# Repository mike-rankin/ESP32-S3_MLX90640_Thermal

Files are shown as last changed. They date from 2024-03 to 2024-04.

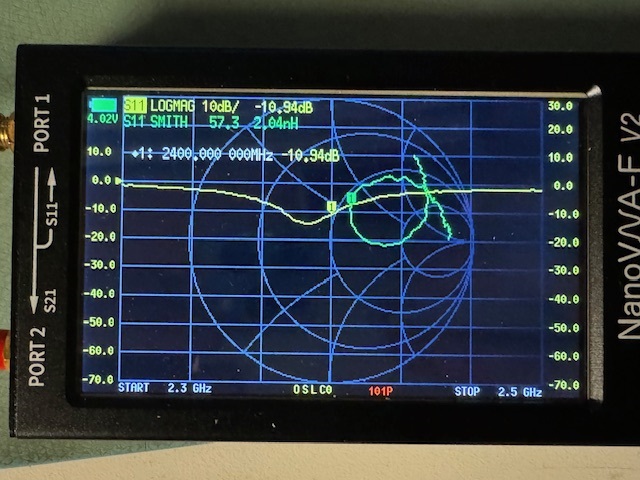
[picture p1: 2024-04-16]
PCB/Antenna_Perfect_Performance.jpg

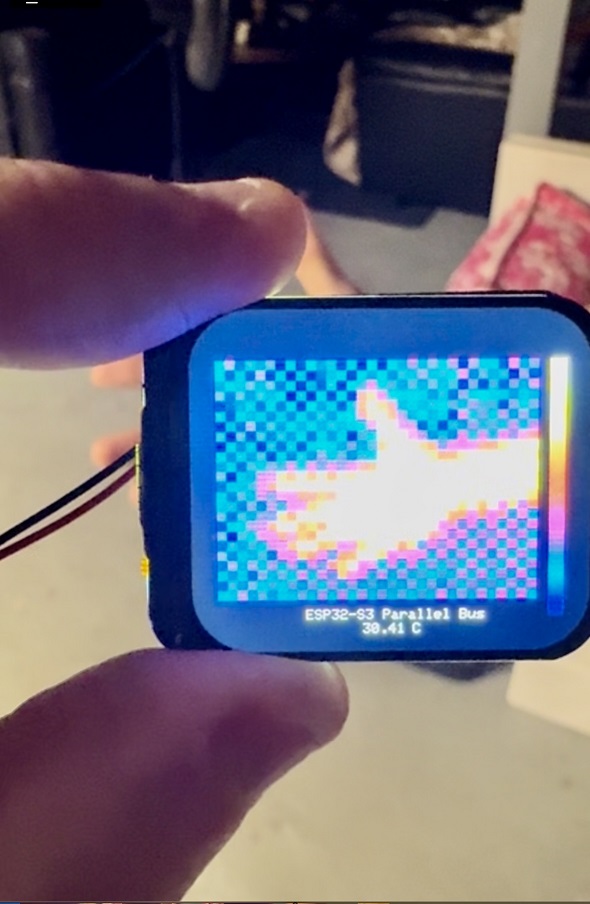
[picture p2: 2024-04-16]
Images/Hand.jpg

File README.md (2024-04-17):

# ESP32-S3_MLX90640_Thermal

An assembled and tested board is available at Tindie: https://www.tindie.com/products/miker/esp32-s3-mlx90640-thermal-image-board/<br/>

This project has gone through several revisions over several months. This latest uses a pcb track antenna instead of the chip type. Tuning has gone well and it seems to perform well. This version uses an ESP32-S3 processor allowing everything to fit on the backside of a 1.69" screen. An 8-bit bus improves the refresh dramatically over traditional spi displays. It is powered by a USB-C connector or small LiPO battery<br/>
Two right angle pushbuttons are on one side if needed and two small vertical ones needed only when first powering up the board to bring up the com port. The thermal code provided is rough but shows basic functionality. Hopefully it can be of some help allowing you to make improvements. The design files are all available if you would like to assemble your own and change the design yourself. <br/>
<br/>

**Hardware used on this board <br/>**
-Processor (ESP32-S3FN8)<br/>
-1.69" LCD (https://www.buydisplay.com/1-69-inch-color-280x240-round-rectangle-ips-tft-lcd-display-panel-st7789)<br/>
-3.3V LDO (HT7833)<br/>
-LiPo charger (MCP73831T-2ACI)<br/>
-LiPo connector (1.25mm JST type)<br/>
-Thermal Sensor (MLX90640ESF-BAB-000-TU)<br/>
-LiPo battery monitor (MAX17048G+)<br/>
<br/>

**FAQ** <br/> 
**How do I updload my own sketch?<br/>** 
**-Plug the board into your pc. If your com port appears and disappears over and over, hold down the B (Boot button), tap on the R (Reset) button, let go of the Boot button. This should hold the com port<br/>**
**-Install the latest Arduino IDE, install the ESP32 Board libraries, Install the sensor libraries, Install an older TFT_eSPI library 2.5.43 or compile issues may appear, delete the User_Setup.h and User_Setup_Select.h files and replace with mine<br/>**
**-Upload your sketch<br/>**
<br/>
**Where do I get a battery?<br/>**
**-Source a 300mAh to 500mAh LiPo with a 1.25mm battery from Aliexpress. Just make sure the positive and negative wires are in the correct locations as noted on the board. If not, they can be removed by lifting the tab and swapping around<br/>**
<br/>
**Why does my battery never charge?<br/>**
**-The charger cannot power the board and charge the battery at the same time. To properly charge the battery turn the device off and leave the USB-C plugged in. The red light will go off once charged<br/>**
<br/>
**Why is this often out of stock?<br/>**
**Each board is hand assembled using a hot plate and hot air wand. Parts are usually purchased in small quantities in case it does not sell. Proper testing, packaging and hardware debugging takes time<br/>**
<br/>
**Do you offer custom designs?<br/>**
**Yes if time allows. Hardware prototype design is my full time job with hobby projects as a fun evening adventure<br/>**
(https://youtube.com/shorts/amKmFCEE5ls?si=_cqpdNFftW1ooPPc") <br/>
<br/>

Hand <br/>
Back <br/>
Rev3_Components <br/>
Size <br/>
Front

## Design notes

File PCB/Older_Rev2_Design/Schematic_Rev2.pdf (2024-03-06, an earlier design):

# USB-CSHLD

VBUS | B4 VBUS | A9 GND B¹ GND A¹²

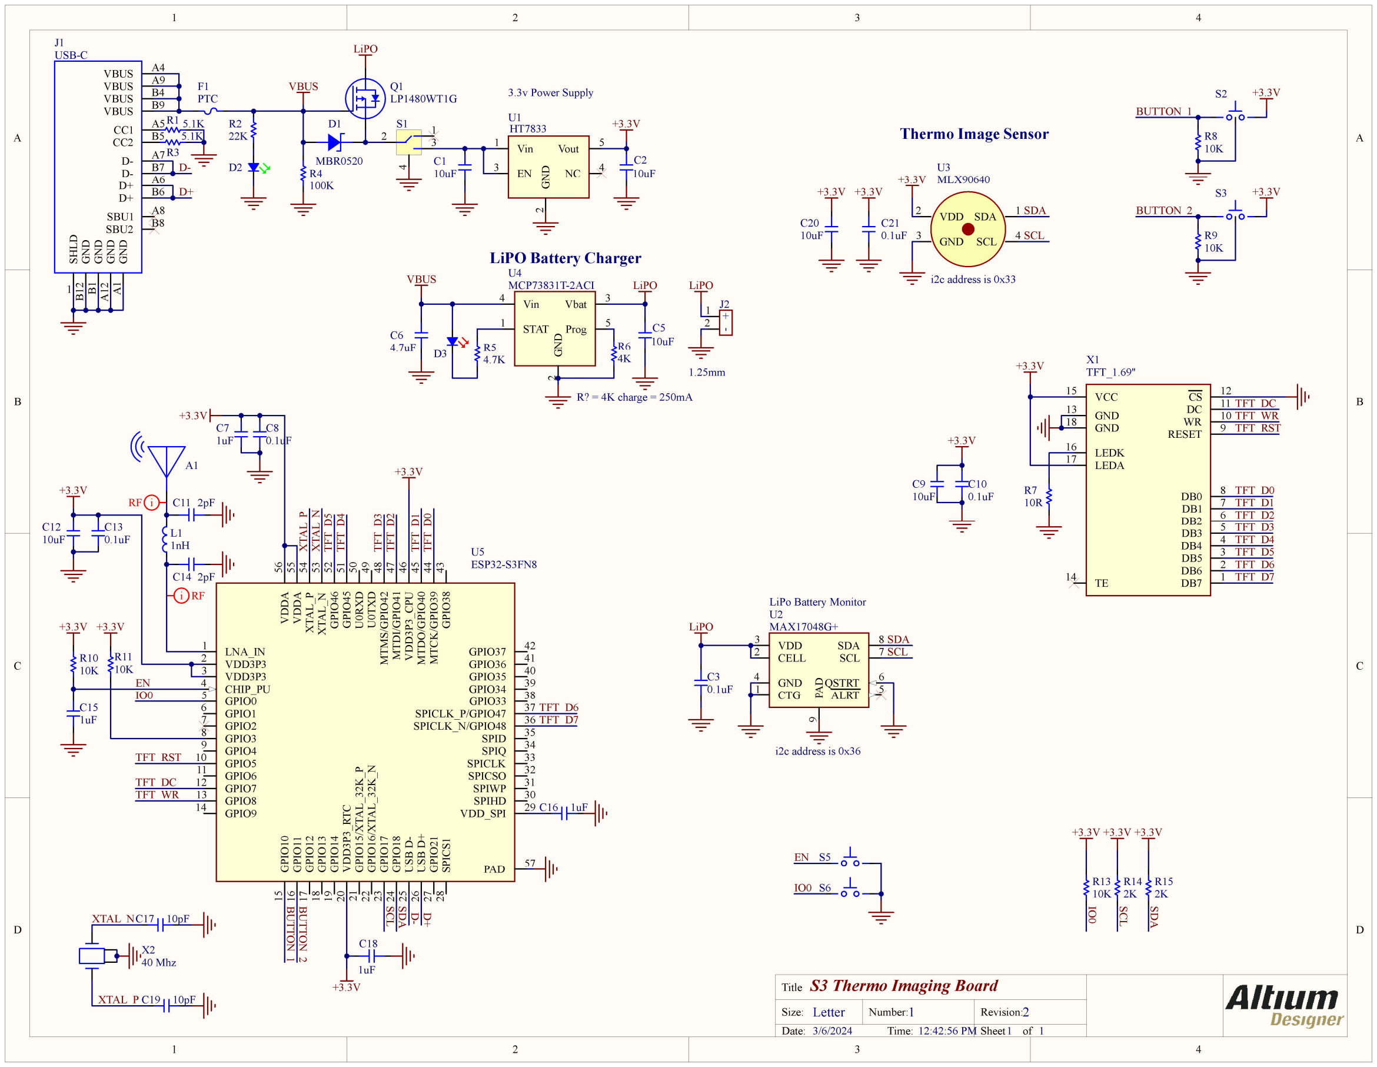
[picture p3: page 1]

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
## S3 Thermo Imaging Board

1 2
3/6/2024 | 12:42:56 PM

Title

Size: | Number:
Date:

Revision:
Time: | Sheet | of

Letter

Vin 1

EN 3 | GND

2

Vout | 5
NC | 4

HT7833

U1

10uF

C2
10uF

C1

3.3v Power Supply

+3.3V

+3.3V

0.1uF

C10
10uF

C9
10R

R7

C16 1uF

+3.3V

+3.3V | XTAL_P XTAL_N

1uF

C7
0.1uF

C8

+3.3V

+3.3V

EN

10K

R10

IO0

+3.3V

1uF

C18

### 40 Mhz

X2

XTAL_P

XTAL_NC17 10pF

C19 10pF

TFT_DC

+3.3V

1uF

C15

10K

R11

+3.3V

TFT_RST

TFT_WR

TFT_D0
TFT_D1
TFT_D2
TFT_D3
TFT_D4
TFT_D5
TFT_D6
TFT_D7 TFT_D⁵ TFT_D⁴ | TFT_D³ TFT_D² | TFT_D¹

TFT_D7 TFT_D⁰

TFT_D6

TFT_DC

TFT_RST

TFT_WR

D-

D+ GND A¹ GND B¹²

VBUS | A4
SBU2 | B8
VBUS | B9

1

CC1 | A5
D- | B7
D+ | A6
D- | A7
D+ | B6
SBU1 | A8
CC2 | B5

J1

D2

PTC

F1

R1 5.1K
5.1K
R3

22K

# R2 D- D+

S5

IO0 S6

EN

10uF

C12

2K

R14
2K

R15

+3.3V SCL SDA | SCL | SDA

0.1uF

C13

C14 2pF

C11 2pF

L1
1nH

i RF

RF i

A1

10K

R13 IO0

## Thermo Image Sensor

+3.3V +3.3V

VBUS | Q1 LP1480WT1G

LiPO

MBR0520

D1

100K

R4

## LiPO Battery Charger

D3

LiPO VBUS

10uF

C5

R? = 4K charge = 250mA

Vin 4

STAT 1 | GND

2

Vbat | 3
Prog | 5

MCP73831T-2ACI

U4

4.7uF

C6

4.7K

R5
4K

R6

1

2 - +J2

LiPO

1.25mm

MLX90640

SDA 1

GND 3

SCL 4

VDD 2

U3
+3.3V

SDA

SCL

i2c address is 0x33

1
2
3 4

S1

0.1uF

C21

+3.3V

10uF

C20

+3.3V

MAX17048G+

CELL 2

VDD 3

CTG 1

SDA | 8
ALRT | 5
QSTRT | 6
SCL | 7
GND 4 | PAD

9

U2

SDA
SCL

i2c address is 0x36

LiPO

0.1uF

C3

LiPo Battery Monitor

ESP32-S3FN8

LNA_IN 1

PAD 57

VDD3P3 2
VDD3P3 3
CHIP_PU 4
GPIO0 5
GPIO1 6
GPIO2 7
GPIO3 8
GPIO4 9
GPIO5 10
GPIO6 11
GPIO7 12 | GPIO¹⁰ 15 GPIO¹¹ 16 GPIO¹² 17 GPIO¹³ 18 GPIO¹⁴ 19 VDD³P³_RTC 20 GPIO¹⁵/XTAL_32K_P 21 GPIO¹⁶/XTAL_32K_N 22 GPIO¹⁷ 23 GPIO¹⁸ 24 USB D⁻ 25 USB D⁺ 26
VDD_SPI | 29
SPIWP | 31 SPICSO | 32 SPICLK | 33 SPIQ | 34 SPID | 35 SPICLK_N/GPIO48 | 36 SPICLK_P/GPIO47 | 37 GPIO33 | 38 GPIO34 | 39 GPIO35 | 40 GPIO36 MTCK/GPIO³⁹ | 41 ⁴⁴ MTDO/GPIO⁴⁰ ⁴⁵ VDD³P³_CPU ⁴⁶ MTDI/GPIO⁴¹ ⁴⁷ MTMS/GPIO⁴² ⁴⁸ U⁰TXD ⁴⁹ U⁰RXD ⁵⁰ GPIO⁴⁵ ⁵¹ GPIO⁴⁶ ⁵² XTAL_N ⁵³ XTAL_P ⁵⁴ VDDA ⁵⁵

GPIO8 13
GPIO9 14 | GPIO²¹ 27 SPICS¹ 28
SPIHD | 30
GPIO37 | 42 GPIO³⁸ ⁴³ VDDA ⁵⁶

U5

TFT_1.69"

LEDA 17

GND 13

VCC 15 | CS | 12
WR | 10 DC | 11
RESET | 9

TE 14

LEDK 16

DB0 | 8
DB1 | 7
DB2 | 6
DB3 | 5

GND 18

DB4 | 4
DB5 | 3
DB6 | 2
DB7 | 1

X1

+3.3V
BUTTON_1

10K

R8

+3.3V
BUTTON_2

10K

R9 BUTTON_1 BUTTON_2

S2

S3

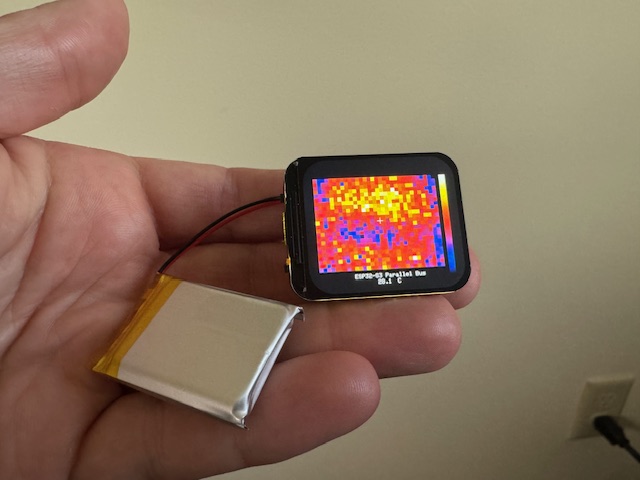
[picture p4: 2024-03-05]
Images/Size.jpg

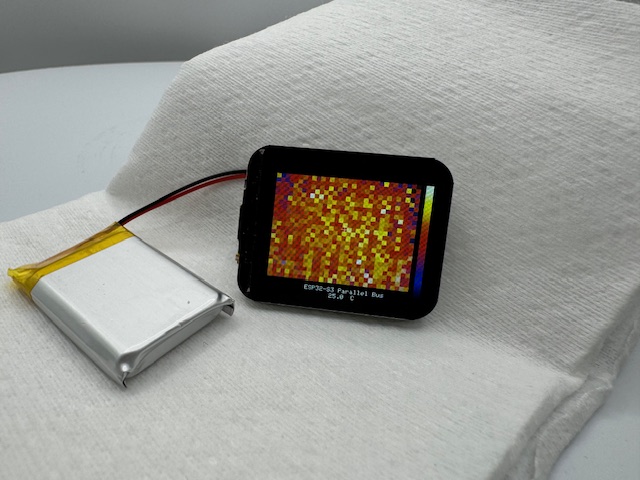
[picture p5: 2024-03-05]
Images/Front.jpg

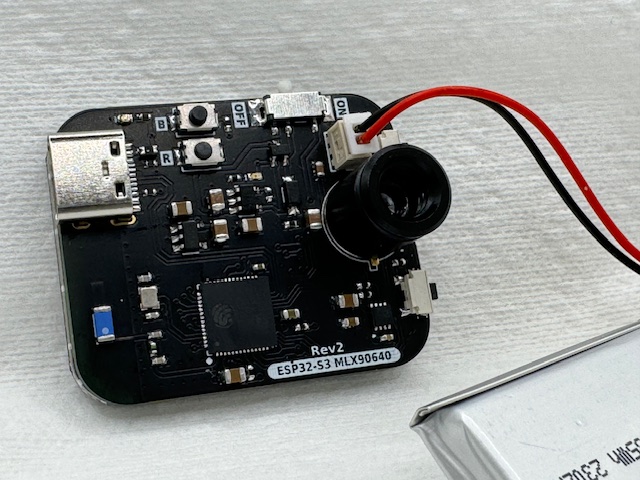
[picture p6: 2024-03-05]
Images/Back.jpg

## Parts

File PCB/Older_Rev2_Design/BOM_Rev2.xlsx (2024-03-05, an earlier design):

Designator | Description | Part_Number | Quantity | Manufacturer | Vendor | Value
A1 | Antenna Chip 2.4Gig | ANT3216LL00R2400A | 1 | YAGEO | LCSC | Chip Antenna
C1, C2, C5, C9, C12, C20 | CAP 10uF 50V 0805, CAP 10uF 0805 |  | 6 |  |  | 10uF
C3, C13 | CAP 0.1uF 0402 |  | 2 |  |  | 0.1uF
C6 | CAP 4.7uF 0805 |  | 1 |  |  | 4.7uF
C7, C18 | CAP 1uF 0603 |  | 2 |  |  | 1uF
C8, C10, C21 | CAP 0.1uF 0603 |  | 3 |  |  | 0.1uF
C11, C14 | CAP TBD 0402, CAP 0402 |  | 2 |  |  | TBD
C15, C16 | CAP 1uF 0402 |  | 2 |  |  | 1uF
C17, C19 | CAP 10pF 0402 |  | 2 |  |  | 10pF
D1 | DIODE SCHOTTKY 20V 500MA SOD-123 | C78746 | 1 | Micro | LCSC | MBR0520
D2 | LED Green 0402 | C74338 | 1 |  | LCSC | Green Led
D3 | LED Red 0402 | C364556 | 1 | Lite-On | LCSC | Red Led
F1 | PTC FUSE 0.5mA hold, 1A trip 0603 | C2982257 | 1 | JDT Fuse | LCSC | PTC
J1 | CONN RECPT USB-C | C165948 | 1 | KHE | LCSC | USB-C
J2 | Micro Conn 2POS 1.25mm Pitch Vertical | 0530470260 | 1 | Molex | Digi-Key | 0530470260
L1 | Inductor TBD |  | 1 |  |  | TBD
Q1 | MOSFET P-CH 20V 1.4A SC-70 | C172434 | 1 | LRC | LCSC | LP1480WT1G
R1, R3 | RES 5.1K 0402 |  | 2 |  |  | 5.1K
R2 | RES 22K 0402 |  | 1 |  |  | 22K
R4 | RES 100K 0402 |  | 1 |  |  | 100K
R5 | RES 4.7K 0402 |  | 1 |  |  | 4.7K
R6 | RES 4K 0402 |  | 1 |  |  | 4K
R7 | RES 10R 0402 |  | 1 |  |  | 10R
R8, R9, R10, R11, R13 | RES 10K 0402 |  | 5 |  |  | 10K
R14, R15 | RES 2K 0402 |  | 2 |  |  | 2K
S1 | SWITCH SLIDE SMD | K3-1296S-E1 | 1 | Korean Hroparts Elec | LCSC | SWITCH SLIDE
S2, S3 | SWITCH TACTILE R/A MICRO | C255808 | 2 | HYP | LCSC | Switch R/A Micro
S5, S6 | SWITCH MOMENTARY | TL1015AF160QG | 2 |  | Digi-Key
U1 | IC LDO 3.3V 0.5A SOT23-5 | C164106 | 1 | Holtek | LCSC | HT7833
U2 | IC BATT MON LI-ION 1CELL 8TDFN | MAX17048G+ | 1 | Analog Devices | Digi-Key
U3 | Thermal Image Sensor TO-39 | MLX90640ESF-BAB-000-TU | 1 | Melexis | Digi-Key | MLX90640
U4 | Charger IC Lithium-Ion/Polymer SOT23-5 | MCP73831T-2ACI/OT | 1 | Microchip | Digi-Key | MCP73831T-2ACI
U5 | WIFI/Bluetooth, 8M PSRAM, QFN-56 7x7 | ESP32-S3FN8 | 1 | Espressif |  | ESP32-S3FN8
X1 | 1.69 INCH TFT 8-BIT PARALLEL BUS | ER-TFT1.69-1 | 1 | BuyDisplay | BuyDisplay | TFT_1.69"
X2 | CRYSTAL 40MHZ 10PF SMD | ECS-400-10-37B2-CKM | 1 | ECS | Digi-Key | 40 Mhz

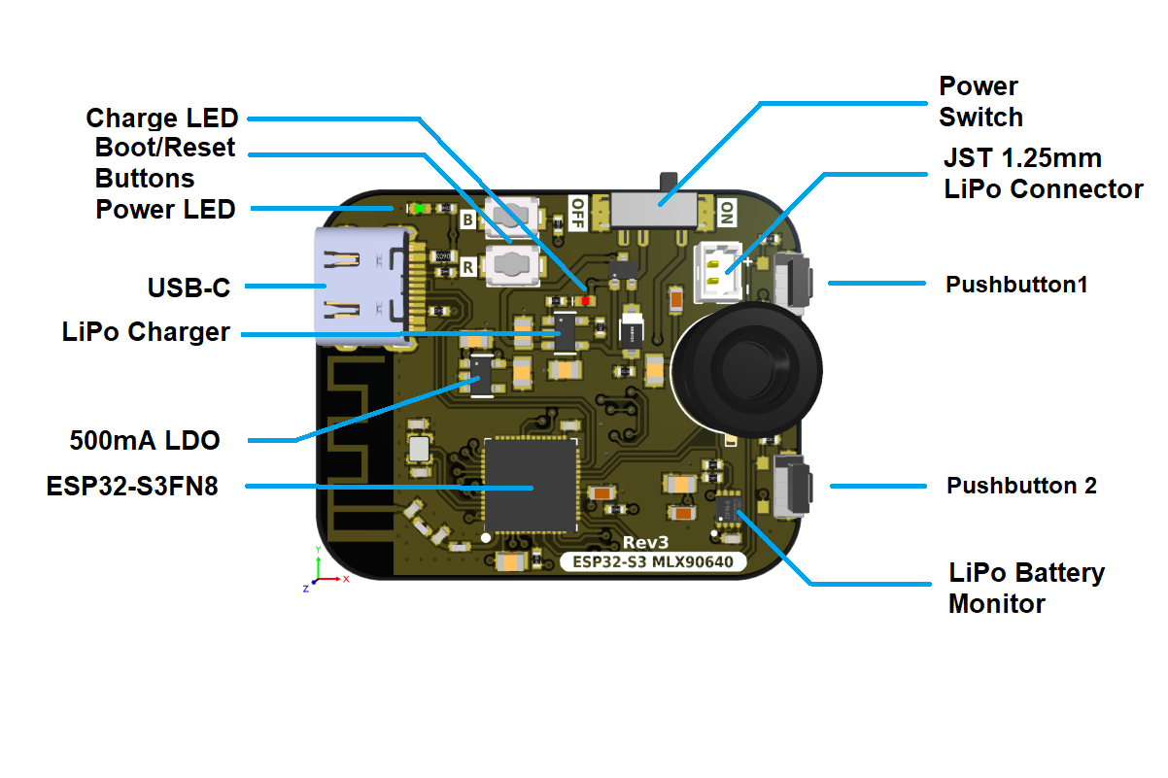
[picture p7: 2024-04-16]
Images/Rev3_Components.png

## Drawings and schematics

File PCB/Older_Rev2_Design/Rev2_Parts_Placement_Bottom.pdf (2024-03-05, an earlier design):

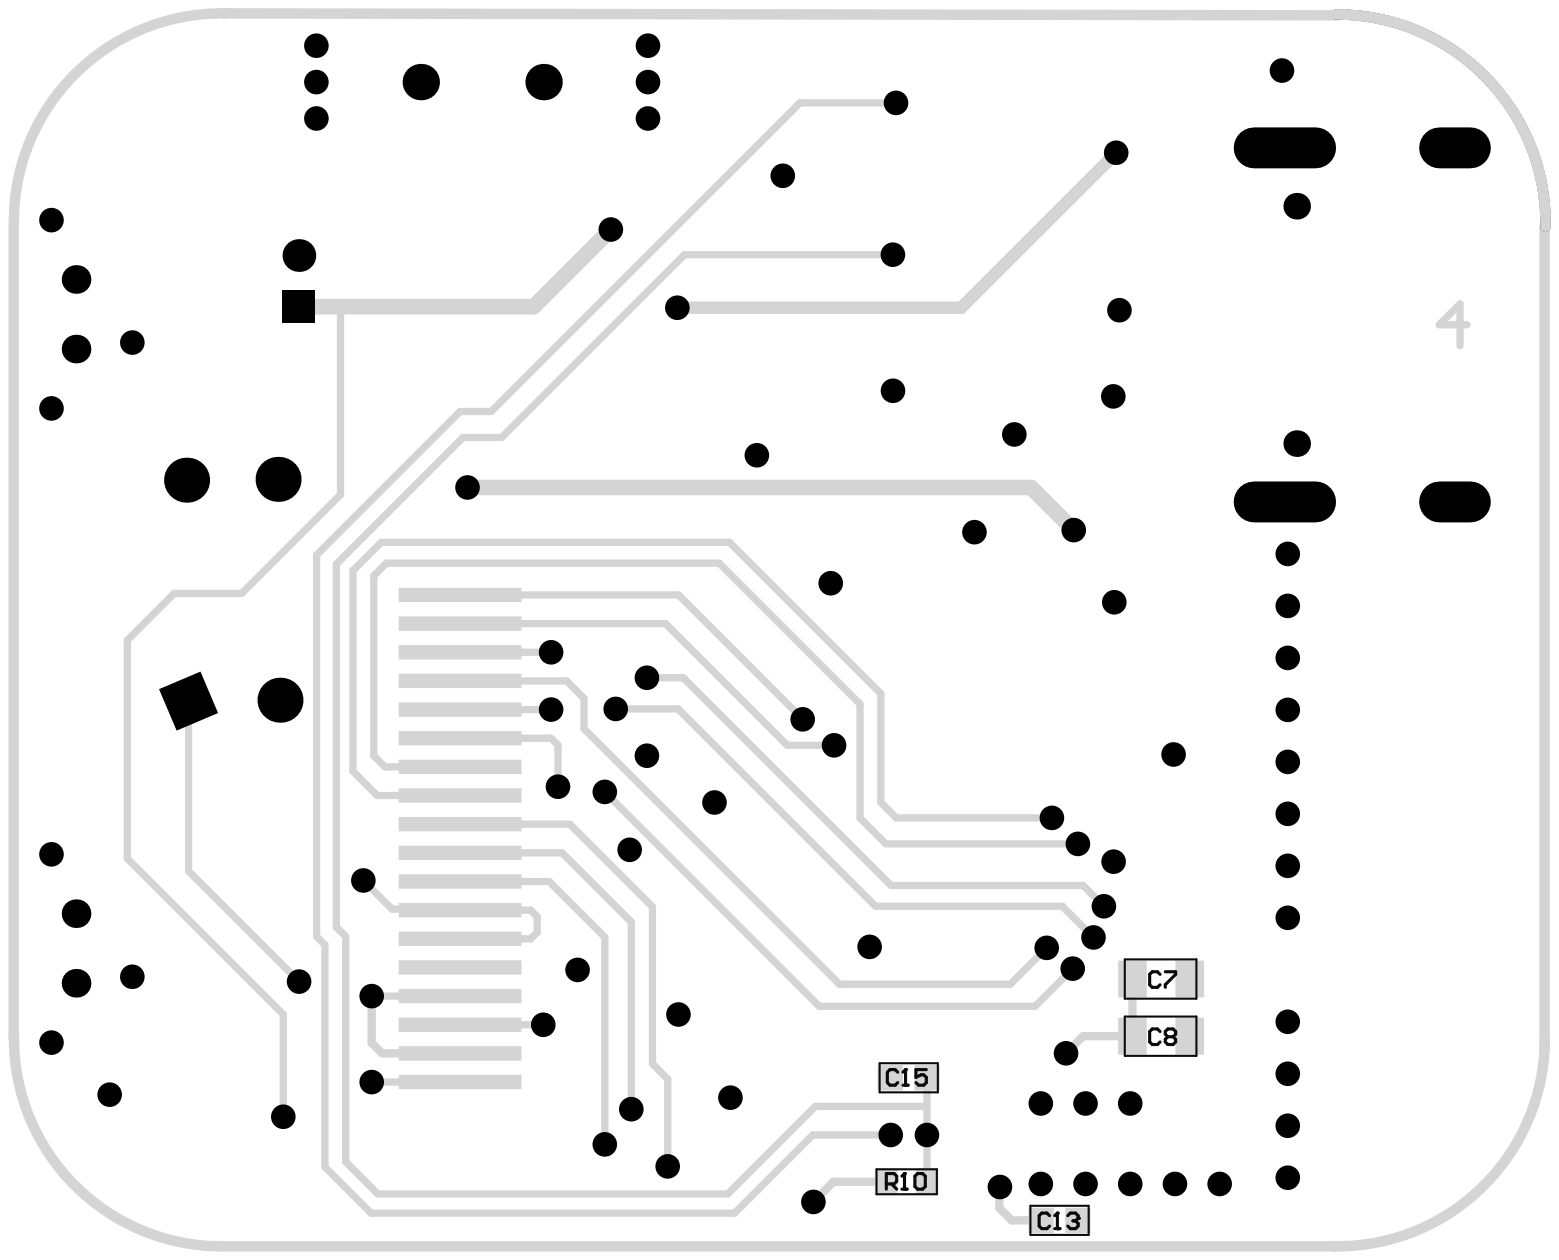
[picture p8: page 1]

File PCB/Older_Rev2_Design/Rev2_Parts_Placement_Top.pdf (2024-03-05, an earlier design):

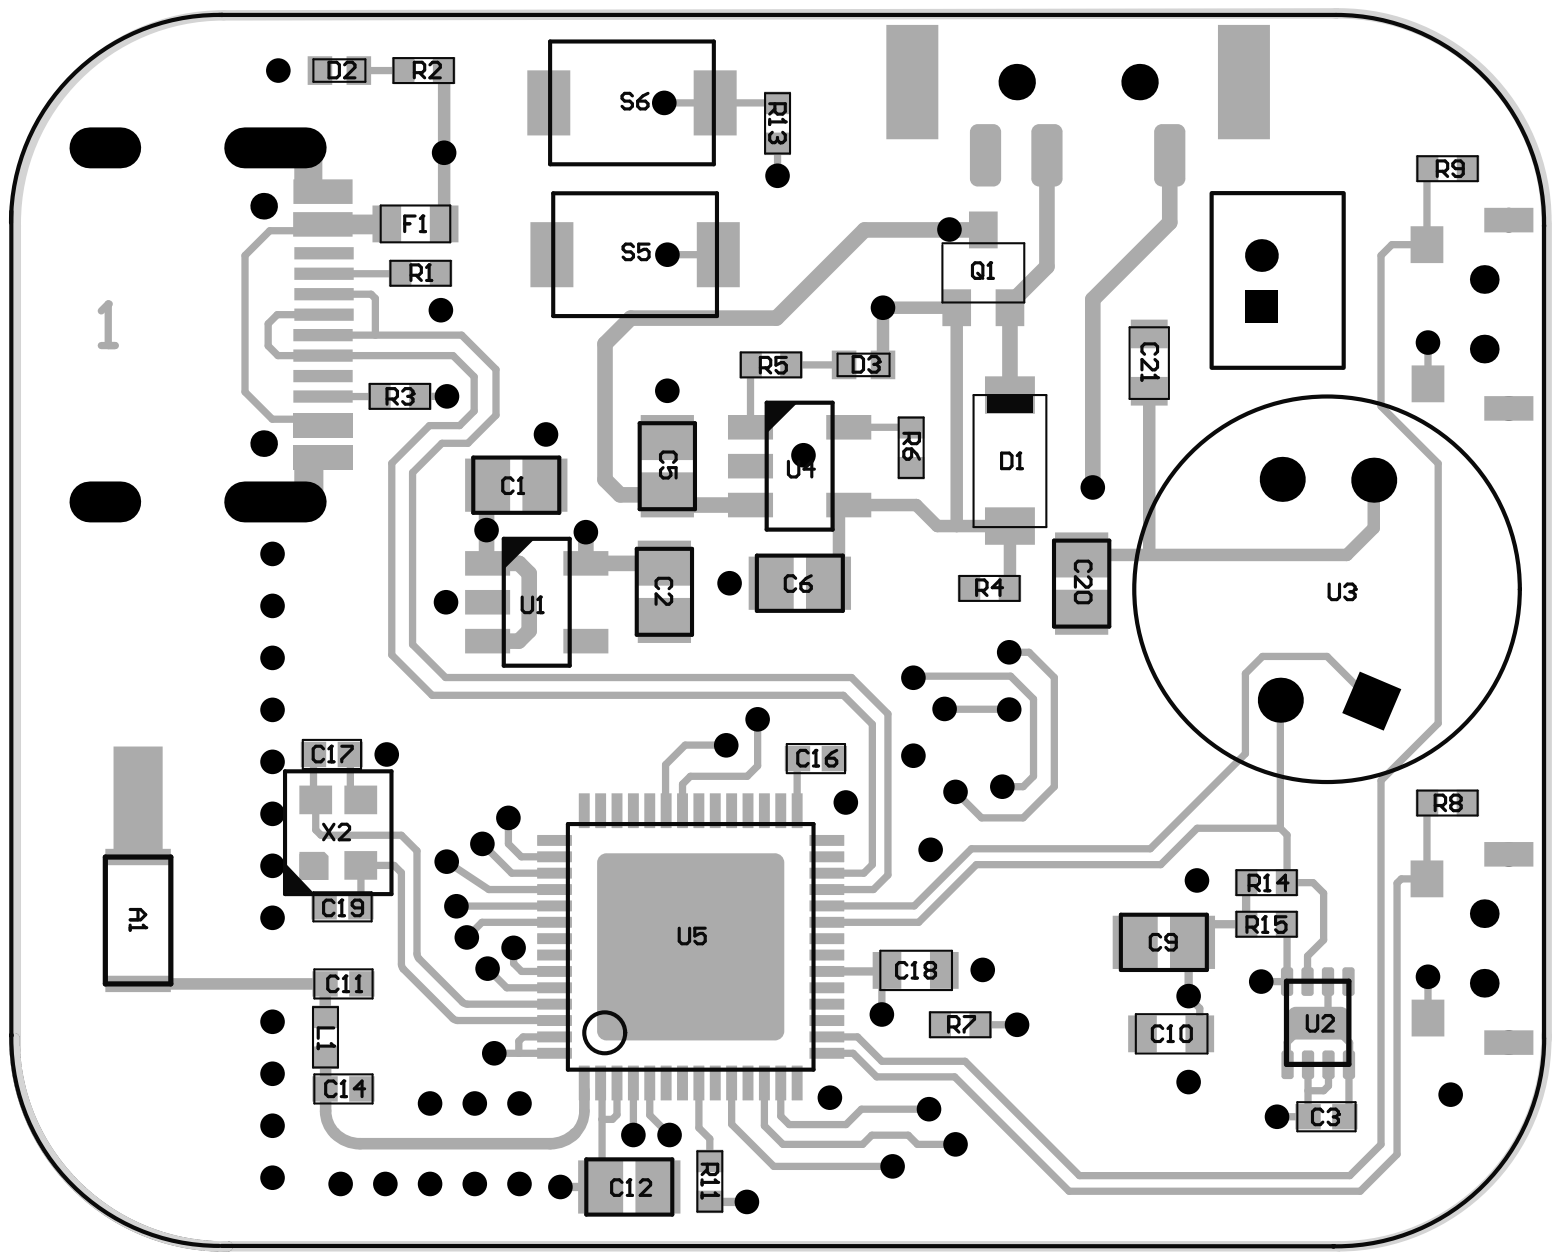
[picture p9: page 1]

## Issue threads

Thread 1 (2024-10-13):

Suggestion for a presence sensor

pardeike, 2024-10-13:
Hi,
I was about to make my own when I stumbled over this project. It’s compact and that’s why I like it. I wonder if you would be interested in making a minimal version that only has the sensor and no large usb contact so I can package it with my own 5V transformer into a 3D case I can make my own. The purpose is to mount it at the ceiling and have it connected to main from the lamp (always on since I use Home Automation). I therefore would not need a screen.

On the software side I got all the basics already working with an Atom S3 and the same thermal sensor also from M5Stack but I want to put such a presence sensor into every room and since I am a developer I could make a nice UX that allows to define zones that one can map to mqtt and thus Home Assistant. I would need a way to flash it though so maybe the usb has to at least exist before mounting it to the ceiling.

/Andreas

mike-rankin, 2024-10-13:
Not a problem Andreas,
I have a few off board usb options when space is tight. Please email me at 0miker0@gmail.com and I can attach the images.

Closed 2024-10-14.

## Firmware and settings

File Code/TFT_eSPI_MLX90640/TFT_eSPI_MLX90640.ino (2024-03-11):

/*

 Has to be an older Boards, ESP32 Rev 2.0.11
 Has to be Library, TFT_eSPI Rev 2.5.34
 The latest does not work

*/

#include <TFT_eSPI.h> 
#include <SPI.h>
#include <Wire.h>
#include "MLX90640_API.h"
#include "MLX90640_I2C_Driver.h"

#define TA_SHIFT 8 //Default shift for MLX90640 in open air

const byte MLX90640_address = 0x33;
static float mlx90640To[768];
paramsMLX90640 mlx90640;

int xPos, yPos;                                // Abtastposition
int R_colour, G_colour, B_colour;              // RGB-Farbwert
int i, j;                                      // Zählvariable
float T_max, T_min;                            // maximale bzw. minimale gemessene Temperatur
float T_center;   

TFT_eSPI tft = TFT_eSPI();  // Invoke library, pins defined in User_Setup.h

void setup(void)
 {
  Serial.begin(115200);
  Wire.begin(18,17); //S3 Parallel
  delay(1000);
  Wire.setClock(800000); //Increase I2C clock speed to 800kHz

  //while (!Serial); //Wait for user to open terminal  //Plug into pc or charger issue fixed by commenting out

  Serial.println("MLX90640 IR Array Example");
  
  if (isConnected() == false)
  {
   Serial.println("MLX90640 not detected at default I2C address. Please check wiring. Freezing.");
   while (1);
  } 
    
  Serial.println("MLX90640 online!");
  //Get device parameters - We only have to do this once
  int status;
  uint16_t eeMLX90640[832];
    
  status = MLX90640_DumpEE(MLX90640_address, eeMLX90640);
  if (status != 0)
       Serial.println("Failed to load system parameters");

  status = MLX90640_ExtractParameters(eeMLX90640, &mlx90640);
  if (status != 0)
  {
   Serial.println("Parameter extraction failed");
   Serial.print(" status = ");
   Serial.println(status);
  }
  //Once params are extracted, we can release eeMLX90640 array
   MLX90640_I2CWrite(0x33, 0x800D, 6401);    // writes the value 1901 (HEX) = 6401 (DEC) in the register at position 0x800D to enable reading out the temperatures!!!
  // ===============================================================================================================================================================
  //MLX90640_SetRefreshRate(MLX90640_address, 0x00); //Set rate to 0.25Hz effective - Works
  //MLX90640_SetRefreshRate(MLX90640_address, 0x01); //Set rate to 0.5Hz effective - Works
  //MLX90640_SetRefreshRate(MLX90640_address, 0x02); //Set rate to 1Hz effective - Works
  //MLX90640_SetRefreshRate(MLX90640_address, 0x03); //Set rate to 2Hz effective - Works
  //MLX90640_SetRefreshRate(MLX90640_address, 0x04); //Set rate to 4Hz effective - Works
  MLX90640_SetRefreshRate(MLX90640_address, 0x05); //Set rate to 8Hz effective - Works at 800kHz
  //MLX90640_SetRefreshRate(MLX90640_address, 0x06); //Set rate to 16Hz effective - fails
  //MLX90640_SetRefreshRate(MLX90640_address, 0x07); //Set rate to 32Hz effective - fails


  tft.init();
  tft.setRotation(3);
  tft.fillScreen(TFT_BLACK);
  //tft.setTextColor(TFT_YELLOW, TFT_BLACK); // Note: the new fonts do not draw the background colour

  
  // draw the colour-scale
  for (i = 0; i < 181; i++)
  {
   getColour(i);
   //tft.drawLine(250, 210 - i, 260, 210 - i, tft.color565(R_colour, G_colour, B_colour)); 
   tft.drawLine(250, 215 - i, 260, 215 - i, tft.color565(R_colour, G_colour, B_colour)); //Over
  } 
  
}

void loop() 
{
  //tft.setTextColor(TFT_GREEN, TFT_BLACK);
  //tft.setCursor (8, 52);
  //tft.print("Test"); // This uses the standard ADAFruit small font

   for (byte x = 0 ; x < 2 ; x++) //Read both subpages
       {
        uint16_t mlx90640Frame[834];
        int status = MLX90640_GetFrameData(MLX90640_address, mlx90640Frame);
    
        if (status < 0)
           {
            Serial.print("GetFrame Error: ");
            Serial.println(status);
           }

        float vdd = MLX90640_GetVdd(mlx90640Frame, &mlx90640);
        float Ta = MLX90640_GetTa(mlx90640Frame, &mlx90640);

        float tr = Ta - TA_SHIFT; //Reflected temperature based on the sensor ambient temperature
        float emissivity = 0.95;

        MLX90640_CalculateTo(mlx90640Frame, &mlx90640, emissivity, tr, mlx90640To);
       }

       
    // determine T_min and T_max and eliminate error pixels
    // ====================================================

    mlx90640To[1*32 + 21] = 0.5 * (mlx90640To[1*32 + 20] + mlx90640To[1*32 + 22]);    // eliminate the error-pixels
    mlx90640To[4*32 + 30] = 0.5 * (mlx90640To[4*32 + 29] + mlx90640To[4*32 + 31]);    // eliminate the error-pixels
    
    T_min = mlx90640To[0];
    T_max = mlx90640To[0];

    for (i = 1; i < 768; i++)
       {
        if((mlx90640To[i] > -41) && (mlx90640To[i] < 301))
           {
            if(mlx90640To[i] < T_min)
               {
                T_min = mlx90640To[i];
               }

            if(mlx90640To[i] > T_max)
               {
                T_max = mlx90640To[i];
               }
           }
        else if(i > 0)   // temperature out of range
           {
            mlx90640To[i] = mlx90640To[i-1];
           }
        else
           {
            mlx90640To[i] = mlx90640To[i+1];
           }
       }


    // determine T_center
    // ==================

    T_center = mlx90640To[11* 32 + 15];    

    // drawing the picture
    // ===================

    for (i = 0 ; i < 24 ; i++)
       {
        for (j = 0; j < 32; j++)
           {
            mlx90640To[i*32 + j] = 180.0 * (mlx90640To[i*32 + j] - T_min) / (T_max - T_min);
                       
            getColour(mlx90640To[i*32 + j]);
            
            //tft.fillRect(217 - j * 7, 35 + i * 7, 7, 7, tft.color565(R_colour, G_colour, B_colour));
            tft.fillRect(235 - j * 7, 35 + i * 7, 7, 7, tft.color565(R_colour, G_colour, B_colour));  //On the S3 board
            //tft.fillRect(297 - j * 7, 35 + i * 7, 7, 7, tft.color565(R_colour, G_colour, B_colour));//großes Bild
            //tft.fillRect(267 - j * 7, 35 + i * 7, 7, 7, tft.color565(R_colour, G_colour, B_colour));//großes Bild
            //tft.fillRect(300 - j * 7, 35 + i * 7, 7, 7, tft.color565(R_colour, G_colour, B_colour));//großes Bild
           }
       }

    //Fadenkreuz
    tft.drawLine(235 - 15*7 + 3.5 - 5, 11*7 + 35 + 3.5, 235 - 15*7 + 3.5 + 5, 11*7 + 35 + 3.5, tft.color565(255, 255, 255));
    tft.drawLine(235 - 15*7 + 3.5, 11*7 + 35 + 3.5 - 5, 235 - 15*7 + 3.5, 11*7 + 35 + 3.5 + 5,  tft.color565(255, 255, 255));
    //tft.drawLine(287 - 15*7 + 3.5 - 5, 11*7 + 35 + 3.5, 287 - 15*7 + 3.5 + 5, 11*7 + 35 + 3.5, tft.color565(255, 255, 255));
    //tft.drawLine(287 - 15*7 + 3.5, 11*7 + 35 + 3.5 - 5, 287 - 15*7 + 3.5, 11*7 + 35 + 3.5 + 5,  tft.color565(255, 255, 255));
 
    //tft.fillRect(260, 25, 37, 10, tft.color565(0, 0, 0));
    //tft.fillRect(260, 205, 37, 10, tft.color565(0, 0, 0));    
    //tft.fillRect(115, 220, 37, 10, tft.color565(0, 0, 0));    

    //tft.setTextColor(TFT_WHITE, tft.color565(0, 0, 0));
    //tft.setCursor(265, 25);//tft.setCursor(265, 25);
    //tft.print(T_max, 1);
    //tft.setCursor(265, 205);//tft.setCursor(265, 205);
    //tft.print(T_min, 1);
    tft.setCursor(120, 220);
    tft.print(T_center, 1);

    //tft.setCursor(300, 25);//tft.setCursor(300, 25);//T Max Oben
    //tft.print("C");
    //tft.setCursor(300, 205);//tft.setCursor(300, 205); //TMin unten
    //tft.print("C");
    tft.setCursor(155, 220);//TFadenkreuz
    tft.print("C");

    //Skala rechts
    /*tft.setCursor(300, 55);//tft.setCursor(300, 25);
    tft.print("300");
    tft.setCursor(300, 85);//tft.setCursor(300, 25);
    tft.print("200");
    tft.setCursor(300, 115);//tft.setCursor(300, 25);
    tft.print("150");
    tft.setCursor(300, 145);//tft.setCursor(300, 25);
    tft.print("100");
    tft.setCursor(300, 175);//tft.setCursor(300, 25);
    tft.print("50");
    */
    tft.setCursor(80, 210);//warum sooo weit links
    tft.print("ESP32-S3 Parallel Bus");
    
    delay(20);
}


// ===============================
// ===== determine the colour ====
// ===============================

void getColour(int j)
   {
    if (j >= 0 && j < 30)
       {
        R_colour = 0;
        G_colour = 0;
        B_colour = 20 + (120.0/30.0) * j;
       }
    
    if (j >= 30 && j < 60)
       {
        R_colour = (120.0 / 30) * (j - 30.0);
        G_colour = 0;
        B_colour = 140 - (60.0/30.0) * (j - 30.0);
       }

    if (j >= 60 && j < 90)
       {
        R_colour = 120 + (135.0/30.0) * (j - 60.0);
        G_colour = 0;
        B_colour = 80 - (70.0/30.0) * (j - 60.0);
       }

    if (j >= 90 && j < 120)
       {
        R_colour = 255;
        G_colour = 0 + (60.0/30.0) * (j - 90.0);
        B_colour = 10 - (10.0/30.0) * (j - 90.0);
       }

    if (j >= 120 && j < 150)
       {
        R_colour = 255;
        G_colour = 60 + (175.0/30.0) * (j - 120.0);
        B_colour = 0;
       }

    if (j >= 150 && j <= 180)
       {
        R_colour = 255;
        G_colour = 235 + (20.0/30.0) * (j - 150.0);
        B_colour = 0 + 255.0/30.0 * (j - 150.0);
       }

   }
   



//Returns true if the MLX90640 is detected on the I2C bus
boolean isConnected()
   {
    Wire.beginTransmission((uint8_t)MLX90640_address);
  
    if (Wire.endTransmission() != 0)
       return (false); //Sensor did not ACK
    
    return (true);
   }   
   

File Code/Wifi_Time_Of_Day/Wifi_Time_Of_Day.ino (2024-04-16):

#include <WiFi.h>
#include "time.h"
#include "sntp.h"

const char* ssid       = "SSID";  
const char* password   = "PASSWORD";    

const char* ntpServer1 = "pool.ntp.org";
const char* ntpServer2 = "time.nist.gov";
const long  gmtOffset_sec = 3600;
const int   daylightOffset_sec = 3600;

const char* time_zone = "CET-1CEST,M3.5.0,M10.5.0/3";  // TimeZone rule for Europe/Rome including daylight adjustment rules (optional)

void printLocalTime()
{
  struct tm timeinfo;
  if(!getLocalTime(&timeinfo)){
    Serial.println("No time available (yet)");
    return;
  }
  Serial.println(&timeinfo, "%A, %B %d %Y %H:%M:%S");
}

// Callback function (get's called when time adjusts via NTP)
void timeavailable(struct timeval *t)
{
  Serial.println("Got time adjustment from NTP!");
  printLocalTime();
}

void setup()
{
  Serial.begin(115200);

  // set notification call-back function
  sntp_set_time_sync_notification_cb( timeavailable );

  /**
   * NTP server address could be aquired via DHCP,
   *
   * NOTE: This call should be made BEFORE esp32 aquires IP address via DHCP,
   * otherwise SNTP option 42 would be rejected by default.
   * NOTE: configTime() function call if made AFTER DHCP-client run
   * will OVERRIDE aquired NTP server address
   */
  sntp_servermode_dhcp(1);    // (optional)

  /**
   * This will set configured ntp servers and constant TimeZone/daylightOffset
   * should be OK if your time zone does not need to adjust daylightOffset twice a year,
   * in such a case time adjustment won't be handled automagicaly.
   */
  configTime(gmtOffset_sec, daylightOffset_sec, ntpServer1, ntpServer2);

  /**
   * A more convenient approach to handle TimeZones with daylightOffset 
   * would be to specify a environmnet variable with TimeZone definition including daylight adjustmnet rules.
   * A list of rules for your zone could be obtained from https://github.com/esp8266/Arduino/blob/master/cores/esp8266/TZ.h
   */
  //configTzTime(time_zone, ntpServer1, ntpServer2);

  //connect to WiFi
  Serial.printf("Connecting to %s ", ssid);
  WiFi.begin(ssid, password);
     WiFi.setTxPower(WIFI_POWER_2dBm);  //Needed for Rev3
  while (WiFi.status() != WL_CONNECTED) {
      delay(500);
      Serial.print(".");
  }
  Serial.println(" CONNECTED");

}

void loop()
{
  delay(5000);
  printLocalTime();     // it will take some time to sync time :)
}

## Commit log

2024-03-05 Added PCB files
    [BOM_Rev2.xlsx]
2024-03-06 Updated files
    [Schematic_Rev2.SchDoc]
2024-04-16 Added Rev3 files
    [BOM_Rev2.xlsx, PCB_Project.PrjPcb, Schematic_Rev2.SchDoc]
2024-04-16 Added step file
    [BOM_Rev2.xlsx, PCB_Project.PrjPcb, Schematic_Rev2.SchDoc]
